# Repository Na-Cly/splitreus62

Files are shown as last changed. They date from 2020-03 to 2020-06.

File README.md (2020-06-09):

# splitreus62 Rev 1.b

- [Atreus](https://github.com/technomancy/atreus) Phil Hagelberg
- [Atreus62](https://github.com/profet23/atreus62) Profet23

All these files were created from scratch, but out of respect for Phil I wanted to GPLv3 the project. 

Thanks to Phil for the staggering measurements from the atreus, and profet23 for the 62 key variant. 

This project uses MIT licensed KiCad footprints from Keebio and the Lily58 project.

Footprints and schematic modified from jorics nrfmicro https://github.com/joric/nrfmicro/

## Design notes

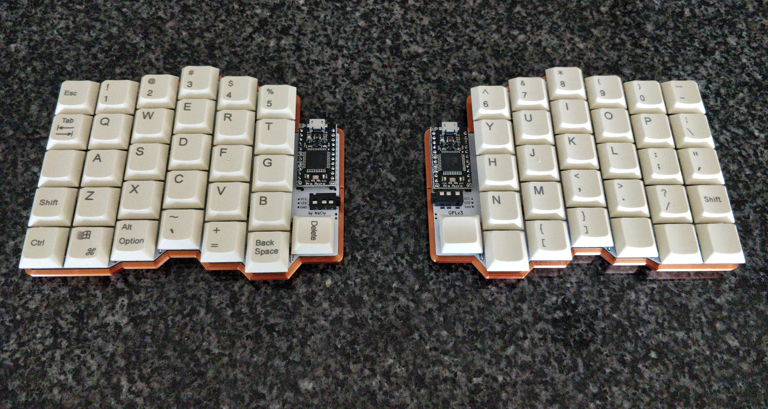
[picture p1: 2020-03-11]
splitreus62.jpg

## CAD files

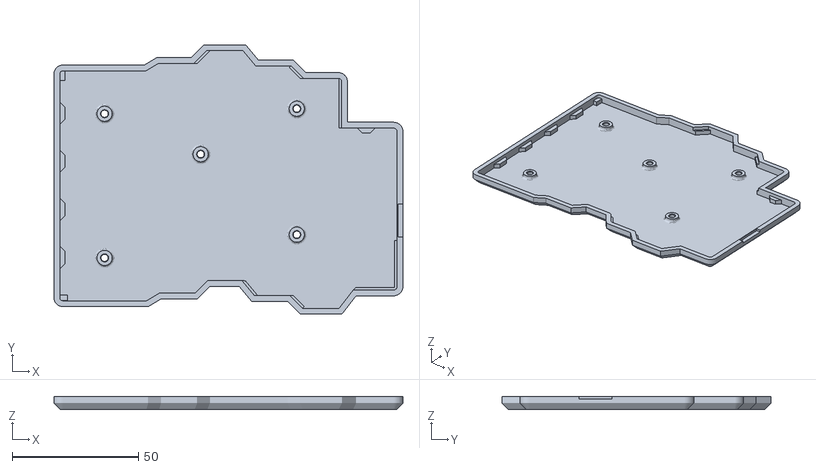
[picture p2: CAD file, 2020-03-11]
low_profile_case/splitreus62_low_profile_case_left.stl
138.0 x 106.5 x 5.15

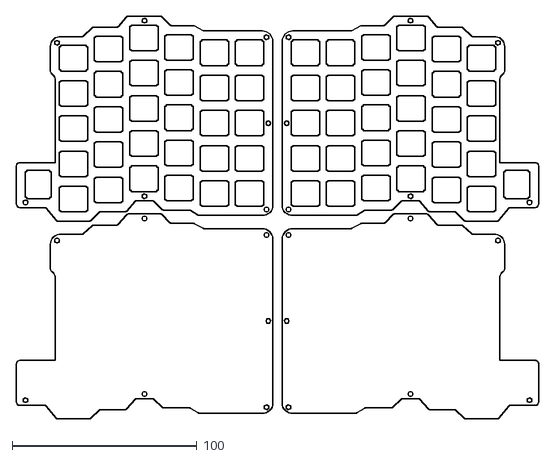
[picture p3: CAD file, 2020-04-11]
sandwich_case_dxf/left_right_switch_bottom.dxf
282.6 x 217.9

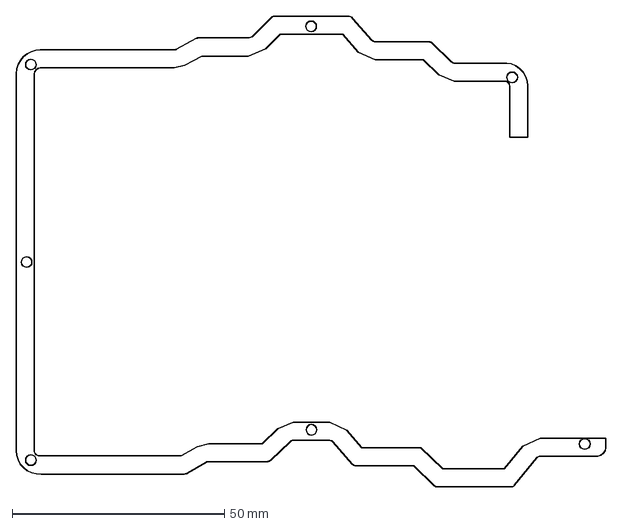
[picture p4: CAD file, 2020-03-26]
sandwich_case_dxf/spacer_left.dxf
138.8 x 110.9 mm

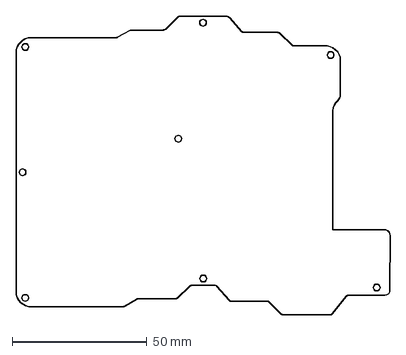
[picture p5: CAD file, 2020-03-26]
sandwich_case_dxf/bottom_plate_left.dxf
138.8 x 110.9 mm

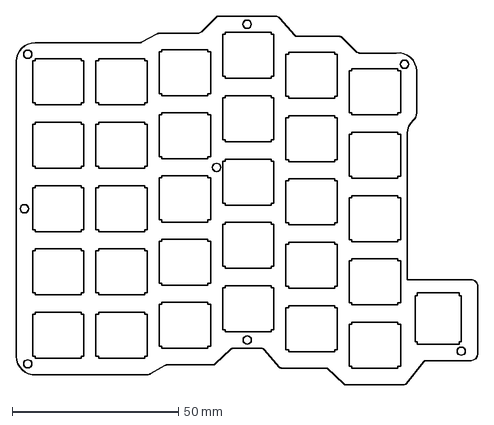
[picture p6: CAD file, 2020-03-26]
sandwich_case_dxf/switch_plate_left.dxf
138.8 x 110.9 mm

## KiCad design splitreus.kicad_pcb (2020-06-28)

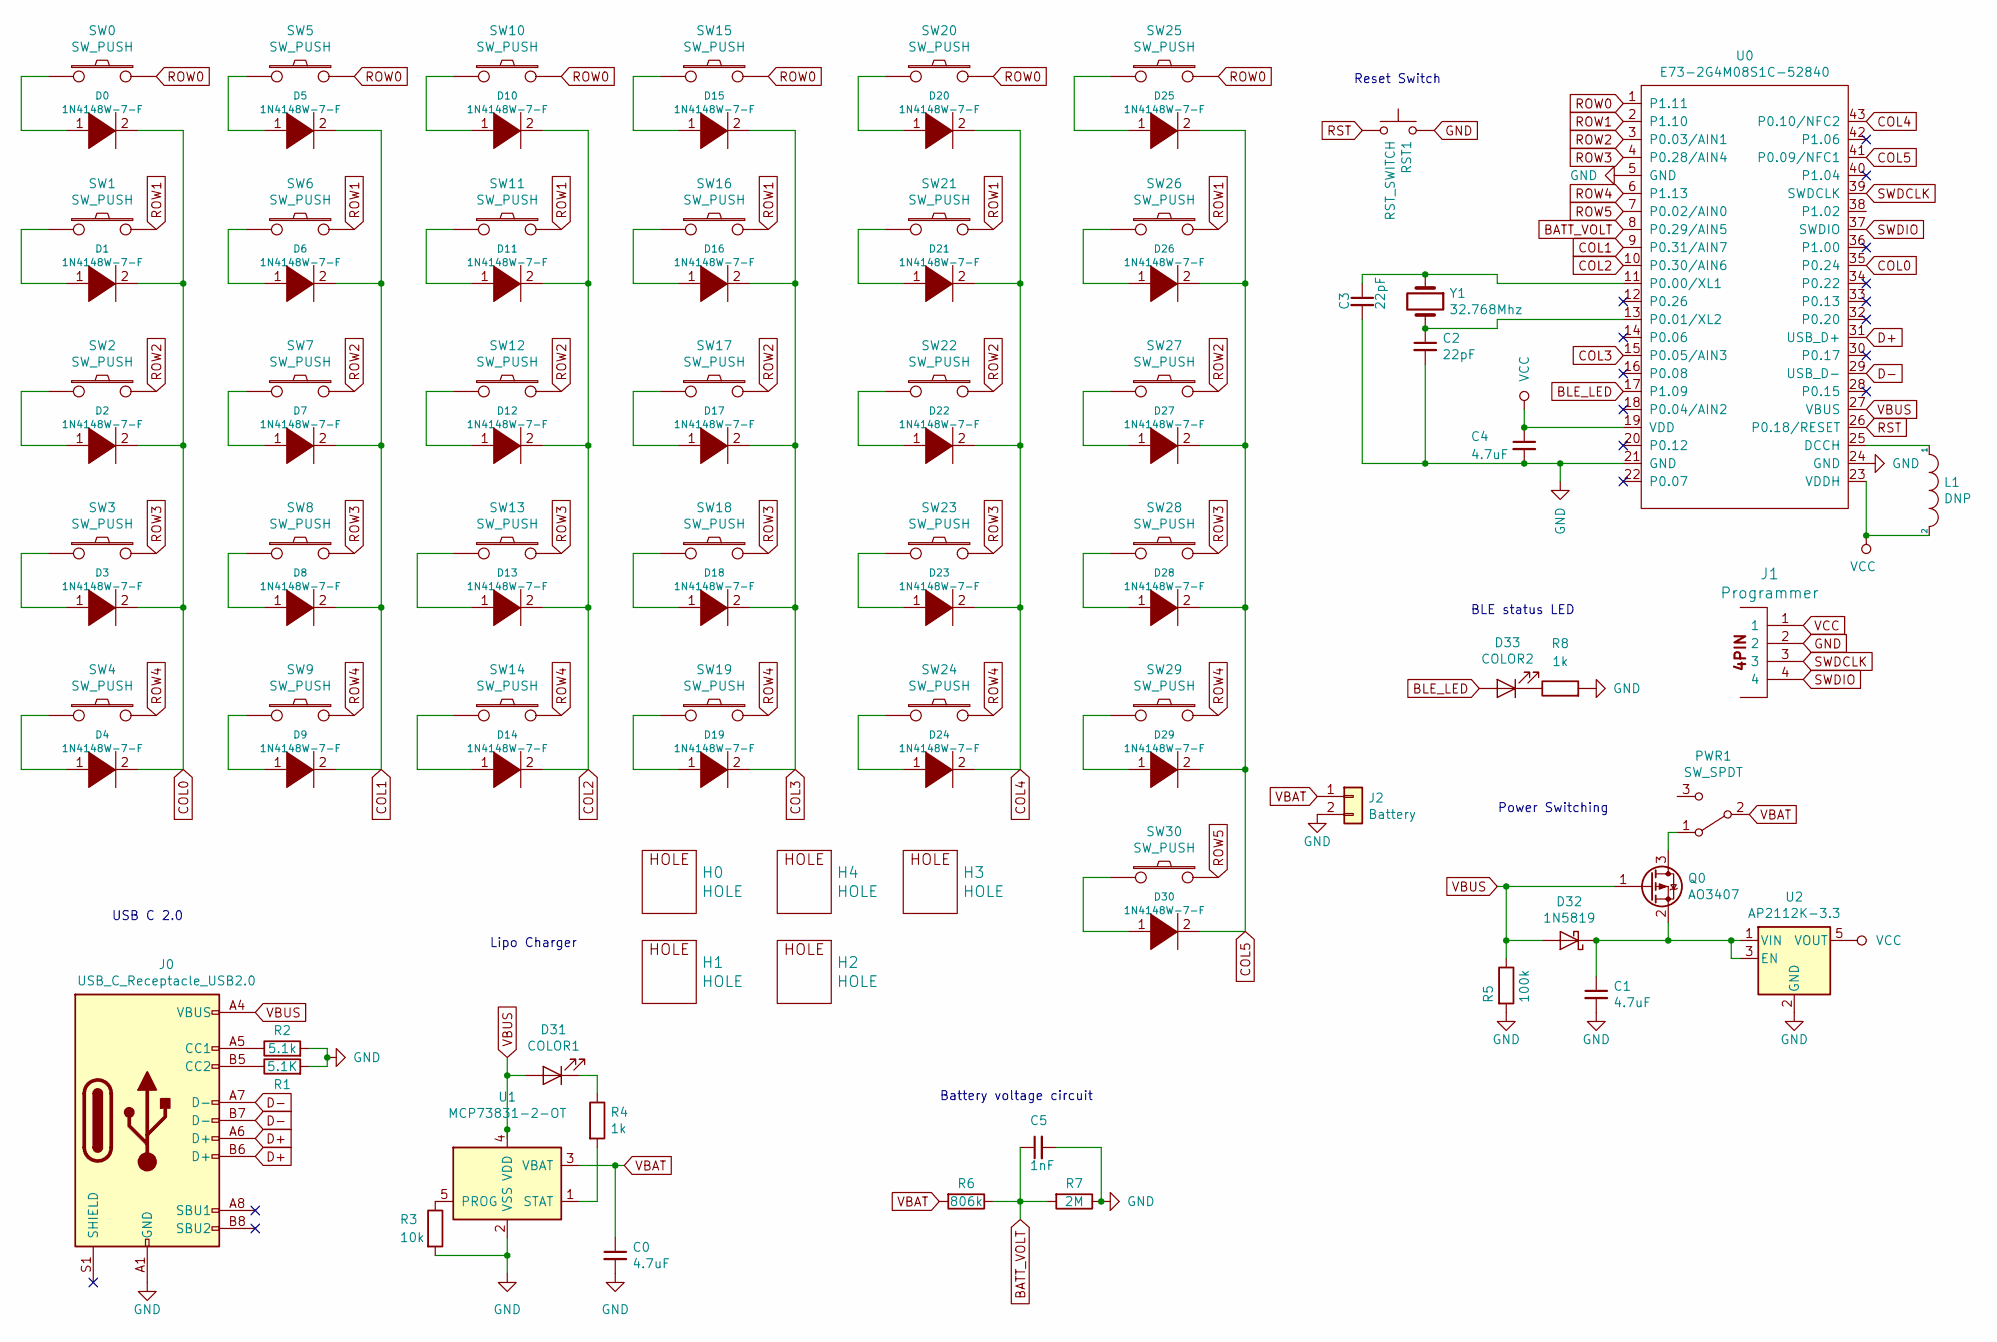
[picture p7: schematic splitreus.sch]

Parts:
C0, C1, C4: 4.7uF; C_0603_1608Metric_better_silk
C2, C3: 22pF; C_0603_1608Metric_better_silk
C5: 1nF; C_0603_1608Metric_better_silk
D0, D1, D2, D3, D4, D5, D6, D7, D8, D9, D10, D11, D12, D13, D14, D15, D16, D17, D18, D19, D20, D21, D22, D23, D24, D25, D26, D27, D28, D29, D30: 1N4148W-7-F; Diode-Hybrid-Back
D31: COLOR1; LED_0603_1608Metric
D32: 1N5819; D_SOD-123
D33: COLOR2; LED_0603_1608Metric
H0, H1, H2, H3, H4: HOLE; MountingHole_3.5mm
J0: USB_C_Receptacle_USB2.0; USB-C-C168688
J1: Programmer; PinHeader_1x04_P2.54mm_Vertical
J2: Battery; JST_EH_S2B-EH_1x02_P2.50mm_Horizontal
L1: DNP
PWR1: SW_SPDT; switch_MSK-12C02_smd
Q0: AO3407; SOT-23
R1: 5.1K; R_0603_1608Metric_better_silk
R2: 5.1k; R_0603_1608Metric_better_silk
R3: 10k; R_0603_1608Metric_better_silk
R4, R8: 1k; R_0603_1608Metric_better_silk
R5: 100k; R_0603_1608Metric_better_silk
R6: 806k; R_0603_1608Metric_better_silk
R7: 2M; R_0603_1608Metric_better_silk
RST1: RST_SWITCH; TACT_SWITCH_TVBP06
SW0, SW1, SW2, SW3, SW4, SW5, SW6, SW7, SW8, SW9, SW10, SW11, SW12, SW13, SW14, SW15, SW16, SW17, SW18, SW19, SW20, SW21, SW22, SW23, SW24, SW25, SW26, SW27, SW28, SW29, SW30: SW_PUSH; MX-Alps-Choc-1U-No-reversible-fixed
U0: E73-2G4M08S1C-52840; E73-2G4M08S1C-52840-NO_THT
U1: MCP73831-2-OT; SOT-23-5
U2: AP2112K-3.3; SOT-23-5
Y1: 32.768Mhz; Crystal_SMD_3215-2Pin_3.2x1.5mm

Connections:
BATT_VOLT: C5.1, R6.1, R7.2, U0.8 (P0.29/AIN5)
BLE_LED: D33.2 (A), U0.17 (P1.09)
COL0: D0.2 (A), D1.2 (A), D2.2 (A), D3.2 (A), D4.2 (A), U0.35 (P0.24)
COL1: D5.2 (A), D6.2 (A), D7.2 (A), D8.2 (A), D9.2 (A), U0.9 (P0.31/AIN7)
COL2: D10.2 (A), D11.2 (A), D12.2 (A), D13.2 (A), D14.2 (A), U0.10 (P0.30/AIN6)
COL3: D15.2 (A), D16.2 (A), D17.2 (A), D18.2 (A), D19.2 (A), U0.15 (P0.05/AIN3)
COL4: D20.2 (A), D21.2 (A), D22.2 (A), D23.2 (A), D24.2 (A), U0.43 (P0.10/NFC2)
COL5: D25.2 (A), D26.2 (A), D27.2 (A), D28.2 (A), D29.2 (A), D30.2 (A), U0.41 (P0.09/NFC1)
D+: J0.A6 (D+), J0.B6 (D+), U0.31 (USB_D+)
D-: J0.A7 (D-), J0.B7 (D-), U0.29 (USB_D-)
GND: C0.2, C1.2, C2.2, C3.2, C4.2, C5.2, J0.A1 (GND), J0.A12 (GND), J0.B1 (GND), J0.B12 (GND), J1.2, J2.2, R1.2, R2.2, R3.2, R5.2, R7.1, R8.2, RST1.2, U0.5 (GND), U0.21 (GND), U0.24 (GND), U1.2 (VSS), U2.2 (GND)
unnamed: C1.1, D32.1 (K), Q0.2 (S), U2.1 (VIN), U2.3 (EN)
unnamed: C2.1, U0.13 (P0.01/XL2), Y1.2
unnamed: C3.1, U0.11 (P0.00/XL1), Y1.1
unnamed: D0.1 (K), SW0.1
unnamed: D1.1 (K), SW1.1
unnamed: D2.1 (K), SW2.1
unnamed: D3.1 (K), SW3.1
unnamed: D4.1 (K), SW4.1
unnamed: D5.1 (K), SW5.1
unnamed: D6.1 (K), SW6.1
unnamed: D7.1 (K), SW7.1
unnamed: D8.1 (K), SW8.1
unnamed: D9.1 (K), SW9.1
unnamed: D10.1 (K), SW10.1
unnamed: D11.1 (K), SW11.1
unnamed: D12.1 (K), SW12.1
unnamed: D13.1 (K), SW13.1
unnamed: D14.1 (K), SW14.1
unnamed: D15.1 (K), SW15.1
unnamed: D16.1 (K), SW16.1
unnamed: D17.1 (K), SW17.1
unnamed: D18.1 (K), SW18.1
unnamed: D19.1 (K), SW19.1
unnamed: D20.1 (K), SW20.1
unnamed: D21.1 (K), SW21.1
unnamed: D22.1 (K), SW22.1
unnamed: D23.1 (K), SW23.1
unnamed: D24.1 (K), SW24.1
unnamed: D25.1 (K), SW25.1
unnamed: D26.1 (K), SW26.1
unnamed: D27.1 (K), SW27.1
unnamed: D28.1 (K), SW28.1
unnamed: D29.1 (K), SW29.1
unnamed: D30.1 (K), SW30.1
unnamed: D31.1 (K), R4.1
unnamed: D33.1 (K), R8.1
unnamed: J0.A5 (CC1), R2.1
unnamed: J0.B5 (CC2), R1.1
unnamed: L1.1, U0.25 (DCCH)
unnamed: PWR1.1 (A), Q0.3 (D)
unnamed: R3.1, U1.5 (PROG)
unnamed: R4.2, U1.1 (STAT)
ROW0: SW0.2, SW5.2, SW10.2, SW15.2, SW20.2, SW25.2, U0.1 (P1.11)
ROW1: SW1.2, SW6.2, SW11.2, SW16.2, SW21.2, SW26.2, U0.2 (P1.10)
ROW2: SW2.2, SW7.2, SW12.2, SW17.2, SW22.2, SW27.2, U0.3 (P0.03/AIN1)
ROW3: SW3.2, SW8.2, SW13.2, SW18.2, SW23.2, SW28.2, U0.4 (P0.28/AIN4)
ROW4: SW4.2, SW9.2, SW14.2, SW19.2, SW24.2, SW29.2, U0.6 (P1.13)
ROW5: SW30.2, U0.7 (P0.02/AIN0)
RST: RST1.1, U0.26 (P0.18/RESET)
SWDCLK: J1.3, U0.39 (SWDCLK)
SWDIO: J1.4, U0.37 (SWDIO)
VBAT: C0.1, J2.1, PWR1.2 (B), R6.2, U1.3 (VBAT)
VBUS: D31.2 (A), D32.2 (A), J0.A4 (VBUS), J0.A9 (VBUS), J0.B4 (VBUS), J0.B9 (VBUS), Q0.1 (G), R5.1, U0.27 (VBUS), U1.4 (VDD)
VCC: C4.1, J1.1, L1.2, U0.19 (VDD), U0.23 (VDDH), U2.5 (VOUT)

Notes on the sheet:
USB C 2.0
Lipo Charger
Power Switching
Reset Switch
Battery voltage circuit
BLE status LED

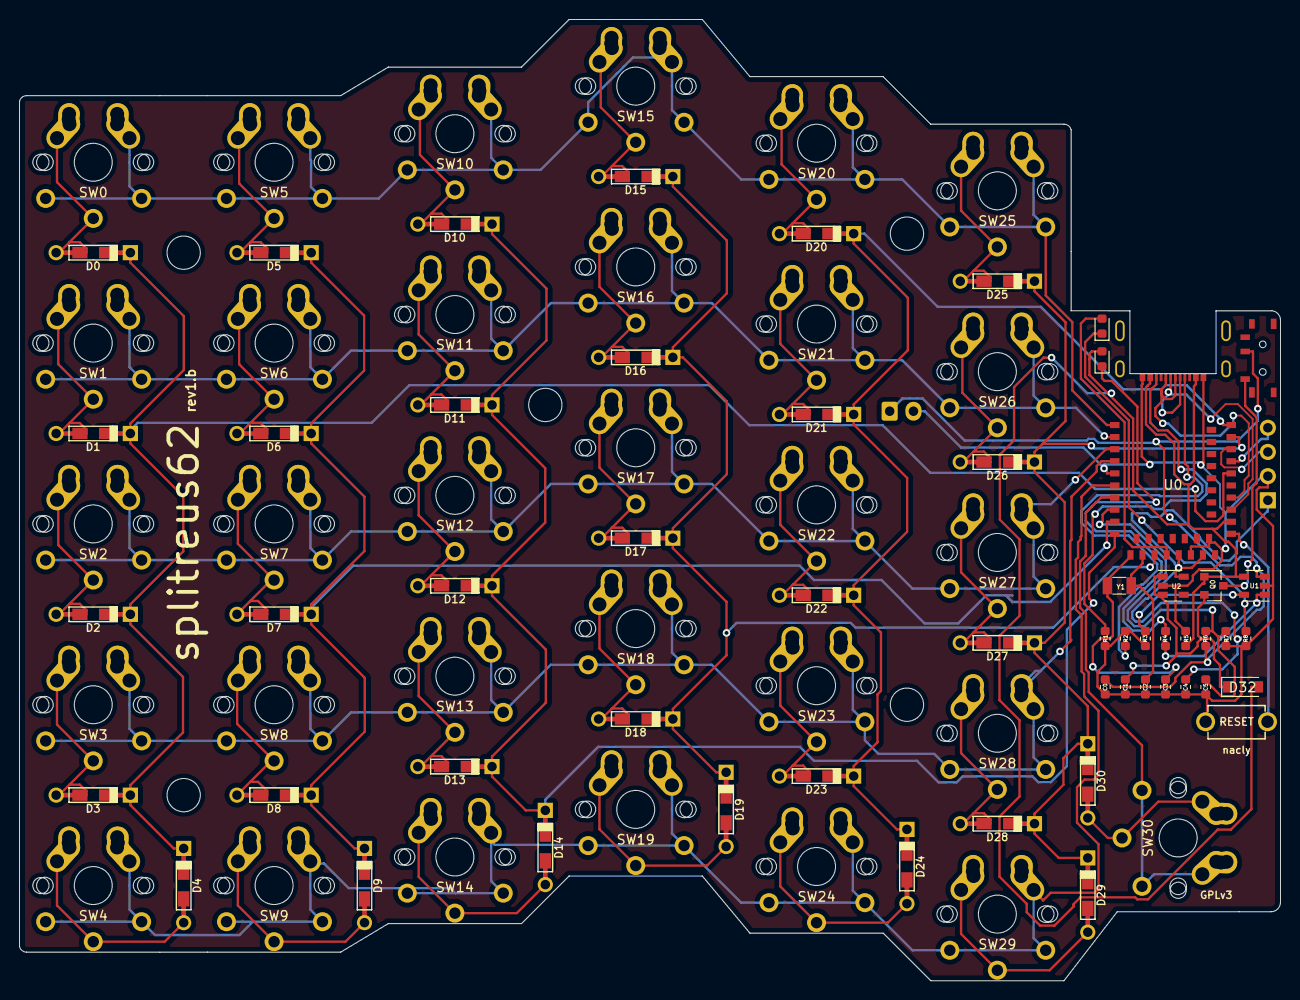
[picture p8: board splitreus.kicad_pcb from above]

Board: 2 copper layers, 132.5 x 101.0 mm, 94 parts (1 on the bottom side), 64 nets.

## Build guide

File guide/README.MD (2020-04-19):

# Build Guide (WIP)
* Thanks to Lucas for the photos used in the build guide. [Github](https://github.com/layertwo)
## Steps
The only order of steps that matter are diodes before switches. Other than that it's pretty much up to you. I prefer the order listed below.

_Note: this build guide uses the low profile case that is compatible with pcb mounted switches. A case is in the works for plate mounted switches. There is a sandwich case available as well, but it is currently only been tested as a 3d print and not as metal._

### I always suggest doing switches last because they are usually the most expensive part of my builds. 
### Suggested order:
 - Diodes
 - TRRS
 - Pro micro headers (multimeter headers if possible to make sure there are no shorted pins)
 - Pro micro to headers
 - Switches

#### Diodes
- through hole diodes can be soldered on top of the pcb, or below. The low profile case requires the diodes be placed on top of the pcb. 
- The black line on the diode will always face the square pad on the pcb.
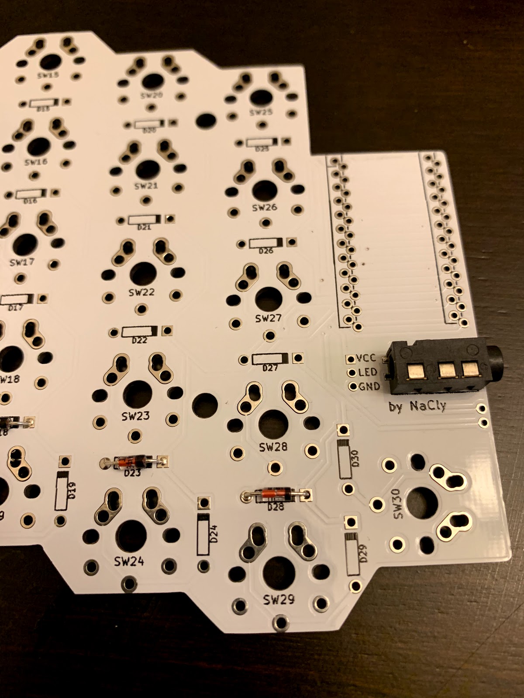
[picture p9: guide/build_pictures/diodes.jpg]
diodes


Make sure to test your diodes before soldering the switches in. If you do not have a multimeter I suggest flashing the pro micros and using a paper clip or wire to short each switch to make sure the diodes are all working.

#### TRRS
- TRRS is straight forward. It only fits in 1 orientation per side if placed on top.
diodes
#### Bottom of TRRS
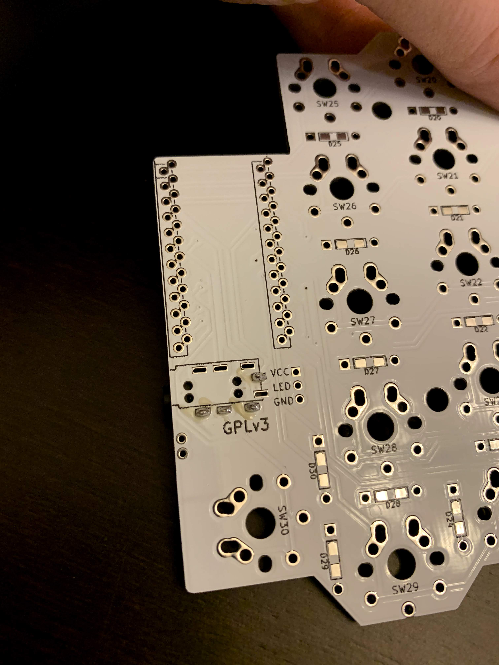
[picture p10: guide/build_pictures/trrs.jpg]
trrs


#### Pro Micro Left and right hands
_NOTE: It is very important that you do not bridge pins from one set of pro micro pads to the other. This could result in the pro micro not powering on, getting stuck in reset mode, or could even end up frying the pro micro. Go easy on the solder._
- I reccomend soldering on headers to the PCB before soldering the headers onto the pro micro. It is much easier to fix any soldering mistakes with just the headers on the PCB. 
- If you have a multimeter it's a good idea to make sure no adjacent pins are connected after soldering. 
- Pro micro always uses the left most set of pads when the pcb is face up.  
- Picutres of left and right sides

#### Left
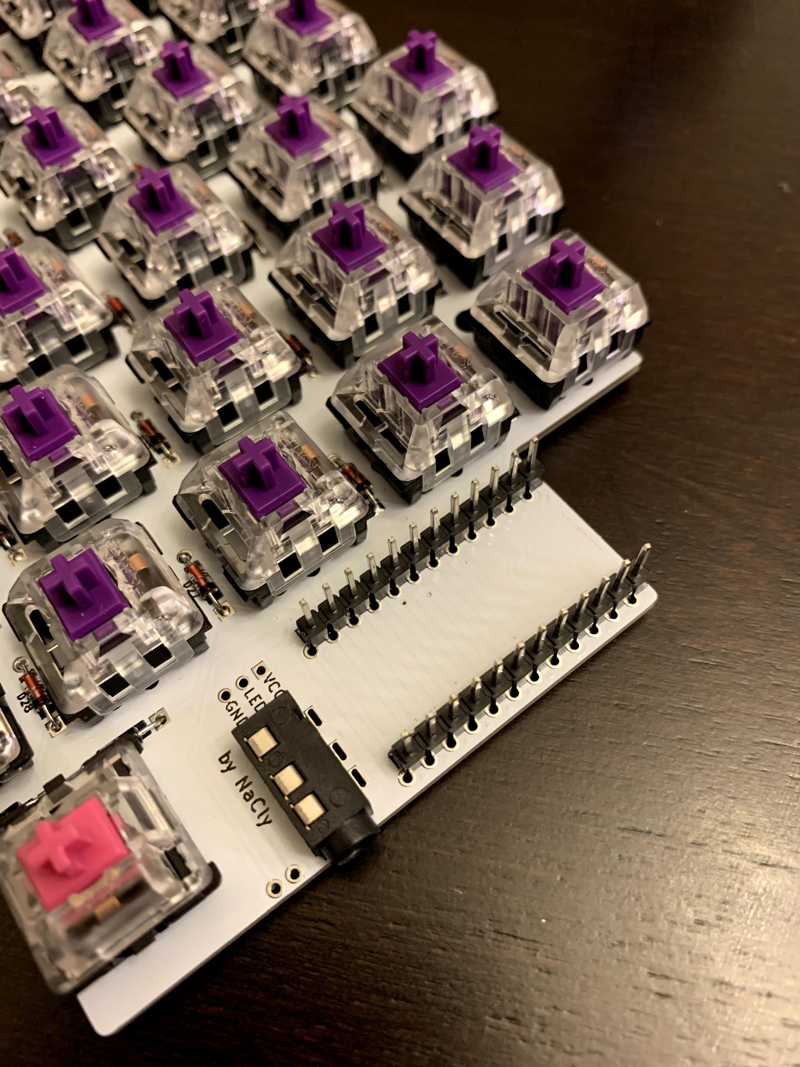
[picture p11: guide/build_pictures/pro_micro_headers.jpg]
left_micro


#### Right
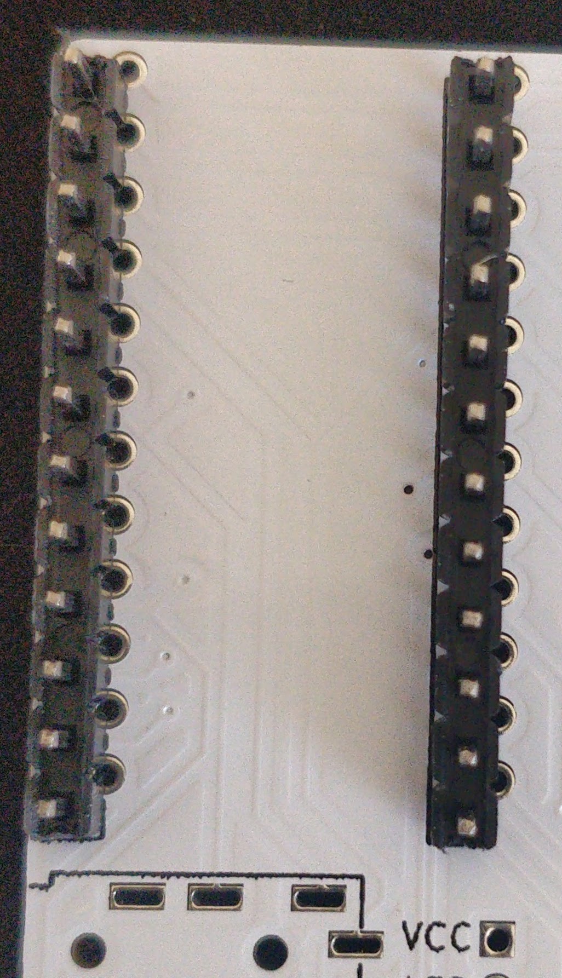
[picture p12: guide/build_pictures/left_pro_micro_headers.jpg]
right_micro


#### Switches
- Nothing special here, except choc switches are roatated 180 degrees. This allowed for a reversible footprint for MX/Alps/Choc.
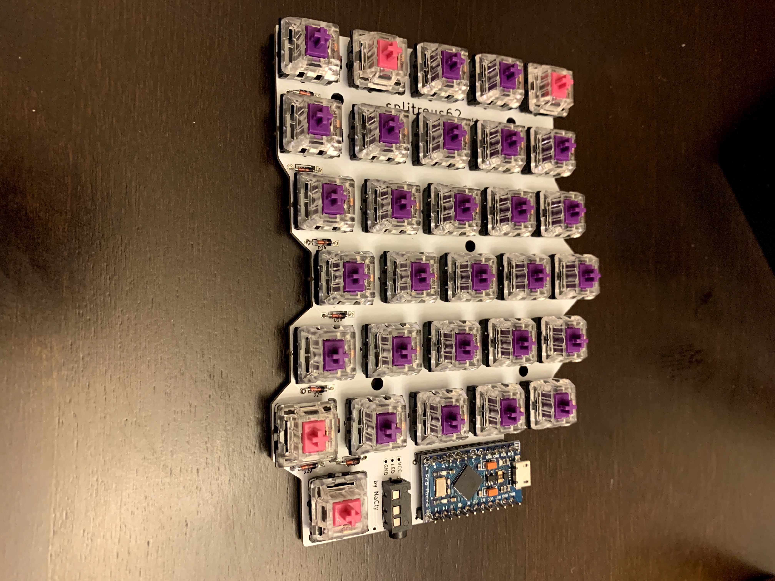
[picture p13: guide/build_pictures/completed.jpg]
switches


#### Case (low profile)
##### _Uses 5 m3x4 per half (m3x5 also work)_
- Before putting on keycaps mount the PCB to the case using the screws.

### Flashing - WIP

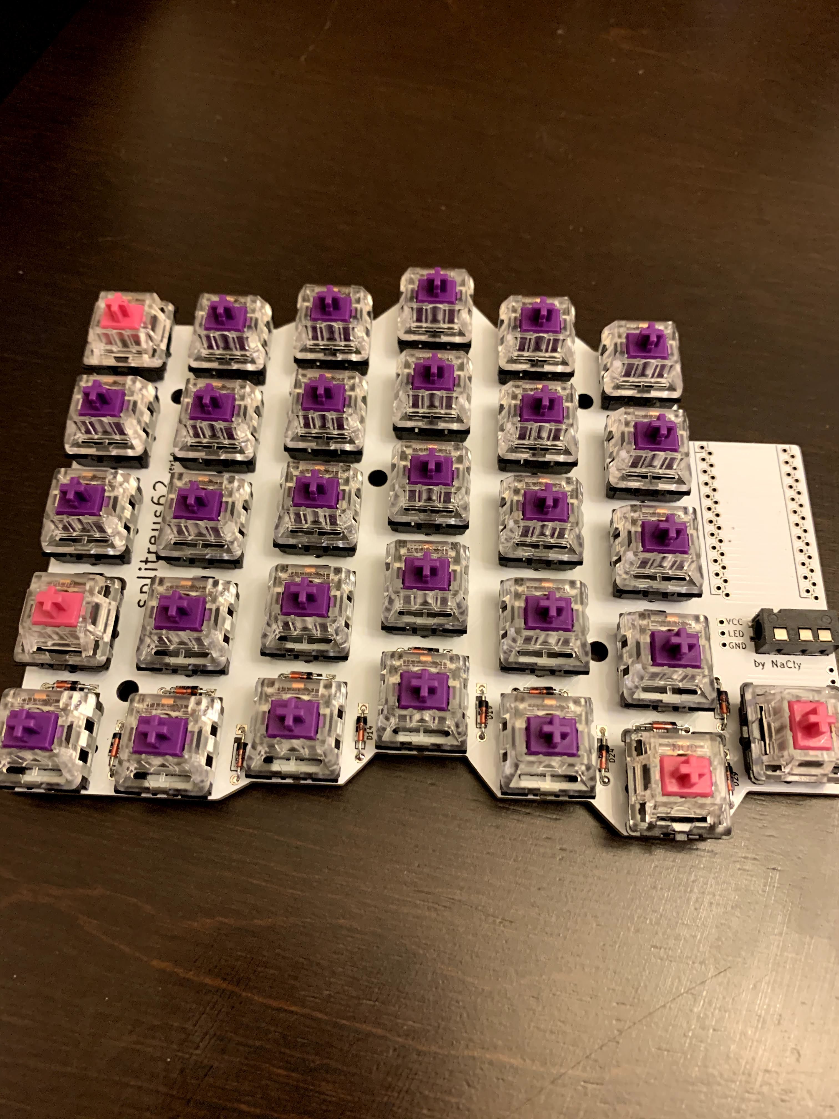
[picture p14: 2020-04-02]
guide/build_pictures/switches.jpg

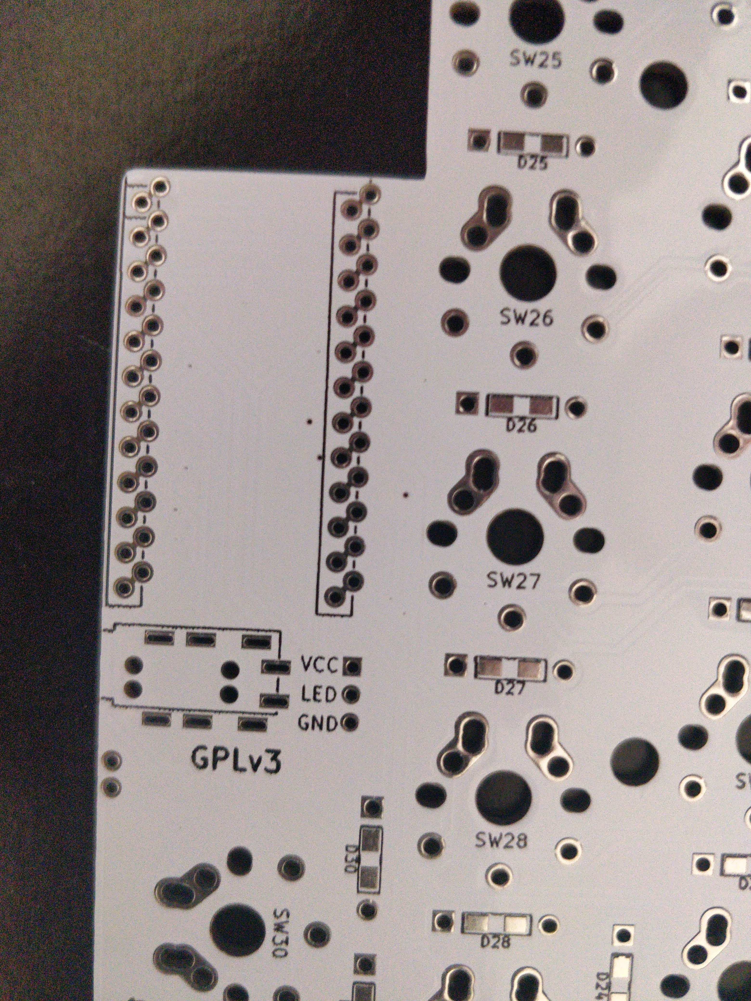
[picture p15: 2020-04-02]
guide/build_pictures/left_pro_micro_pins.jpg

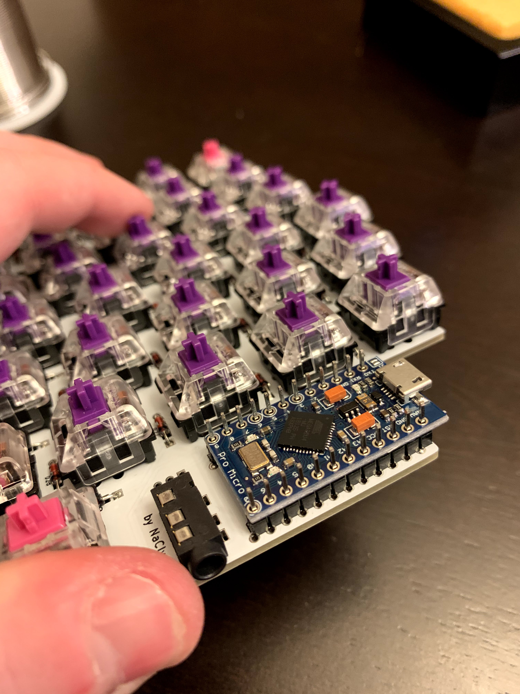
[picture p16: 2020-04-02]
guide/build_pictures/pro_micro.jpg

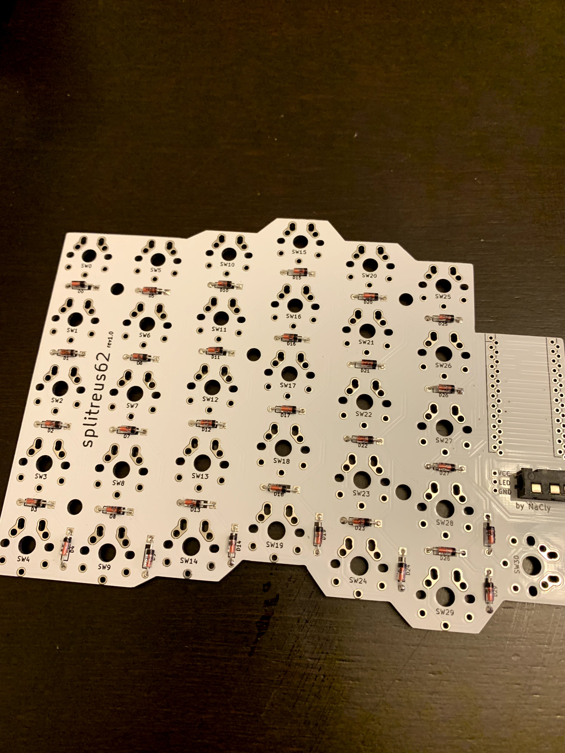
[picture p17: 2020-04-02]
guide/build_pictures/diodes_2.jpg

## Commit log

2020-03-10 Intial Commit
    [splitreus.kicad_pcb, splitreus.sch]
2020-04-11 updated from cm to mm
    [left_right_switch_bottom.dxf]
